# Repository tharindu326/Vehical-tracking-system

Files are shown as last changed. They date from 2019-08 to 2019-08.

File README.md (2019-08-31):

# Vehical-tracking-system

System will detect vehicle’s movements using the vibrations of vehicle and then notify the owner in any case of unidentified movements.

Here I used Peizo to identify vibrations using amplified voltage variations, GPS module (Ublox neo-6m) to identify the coordinates of the location and then GSM (SIM800) module to transmit the data to the mobile device.

And used a mobile application (Android) to request the real time location of the vehicle at any time. And initiation of the phone number and activation can be done using the app as well as it also allows the owner to turn on and off the system at any time.

Arduino UNO was used as the microcontroller and Android studio was used to program the application. Buck converter is used to power up the GPS and GSM modules since its slightly power hungry. Vehicle GPS antenna was used to achieve  more reliable signal strength.

Open Source Licence

Feel free to use this codes and let me know your comments.

[Author] Tharindu Ekanayake _ tharindu326@gmail.com

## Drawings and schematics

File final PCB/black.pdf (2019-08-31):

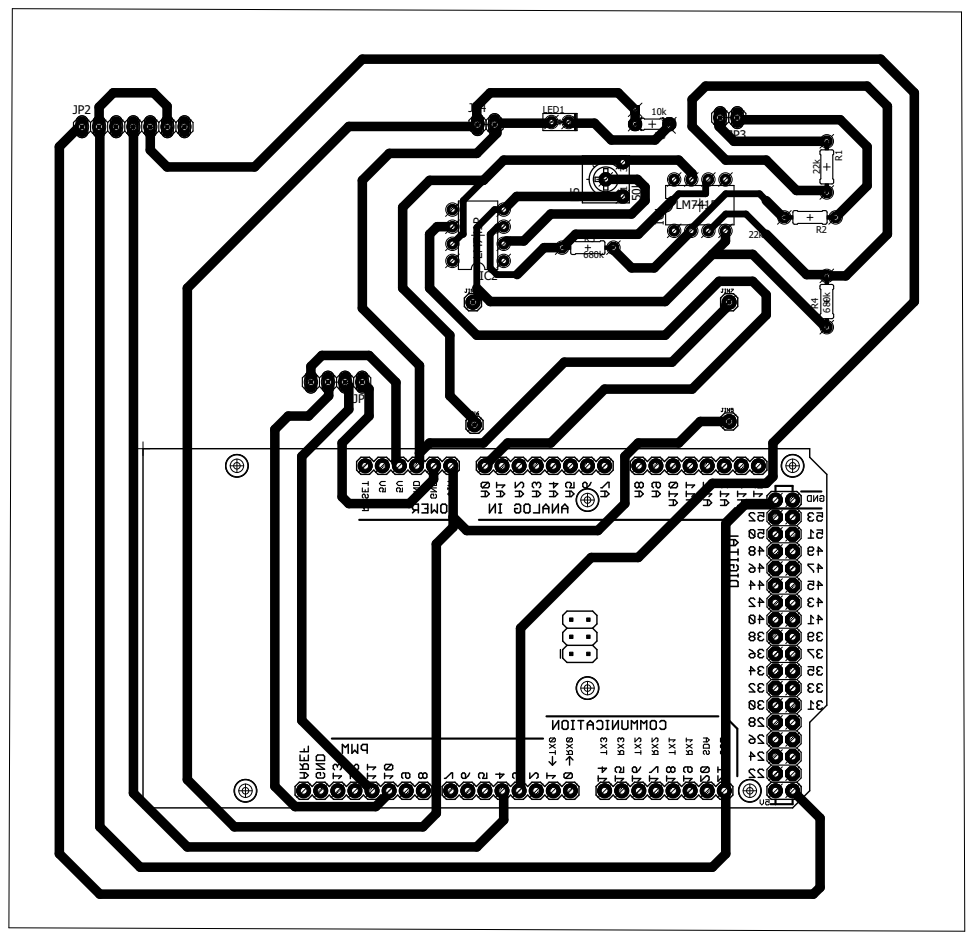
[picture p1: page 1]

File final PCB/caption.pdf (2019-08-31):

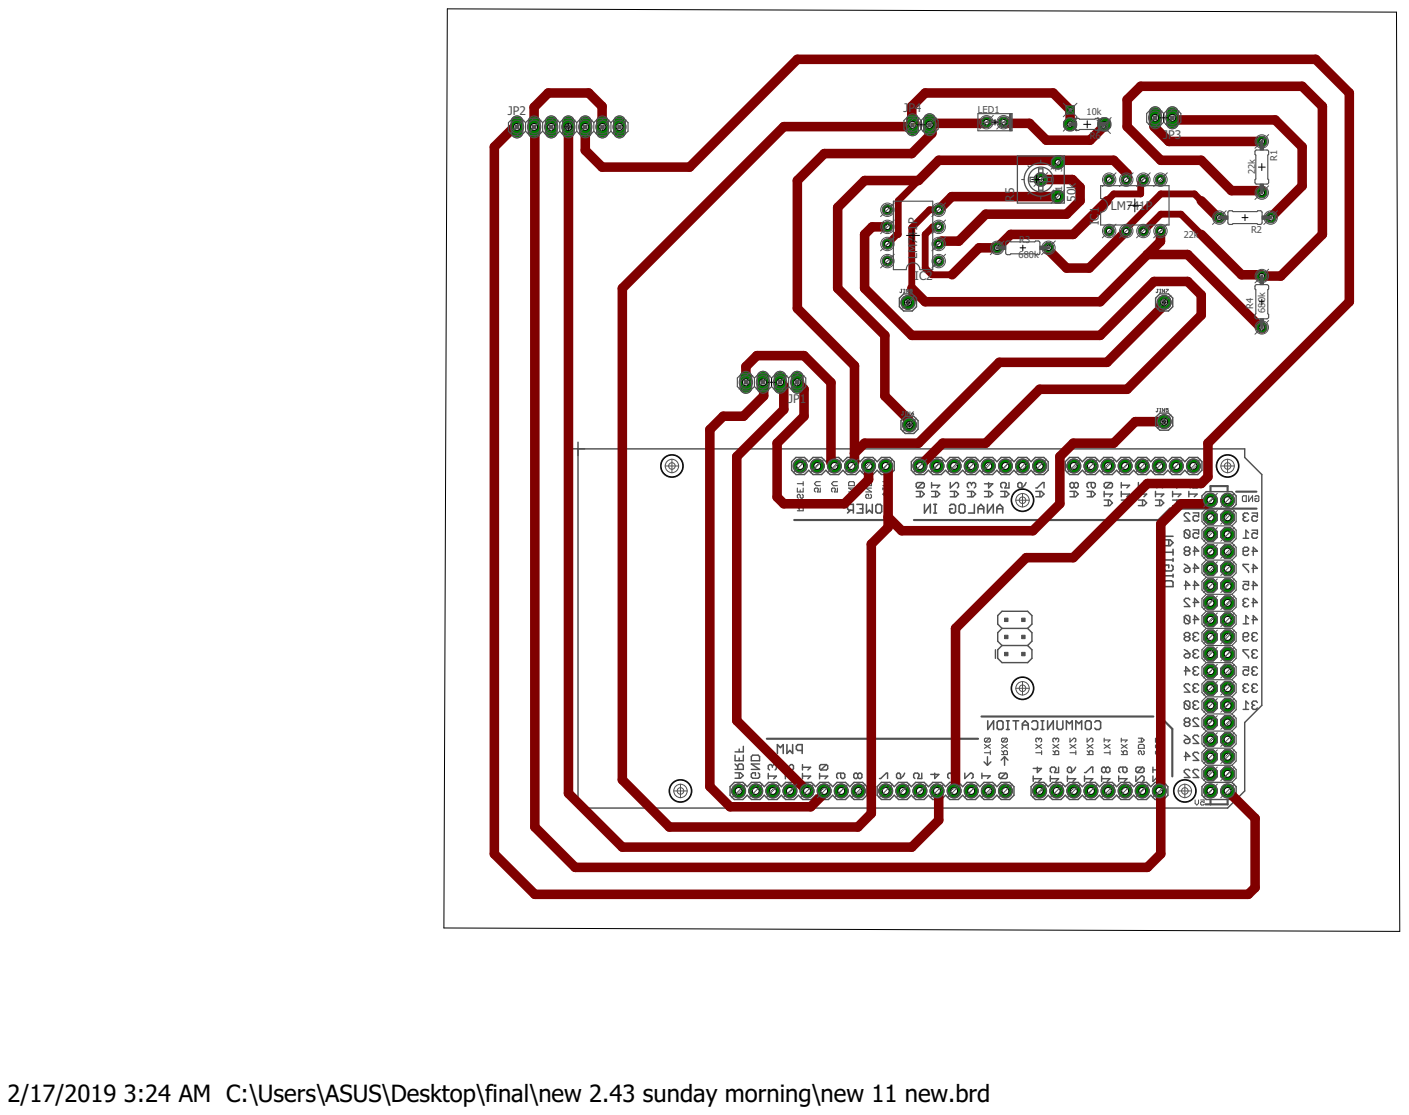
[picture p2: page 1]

2/17/2019 3:24 AM C:\Users\ASUS\Desktop\final\new 2.43 sunday morning\new 11 new.brd

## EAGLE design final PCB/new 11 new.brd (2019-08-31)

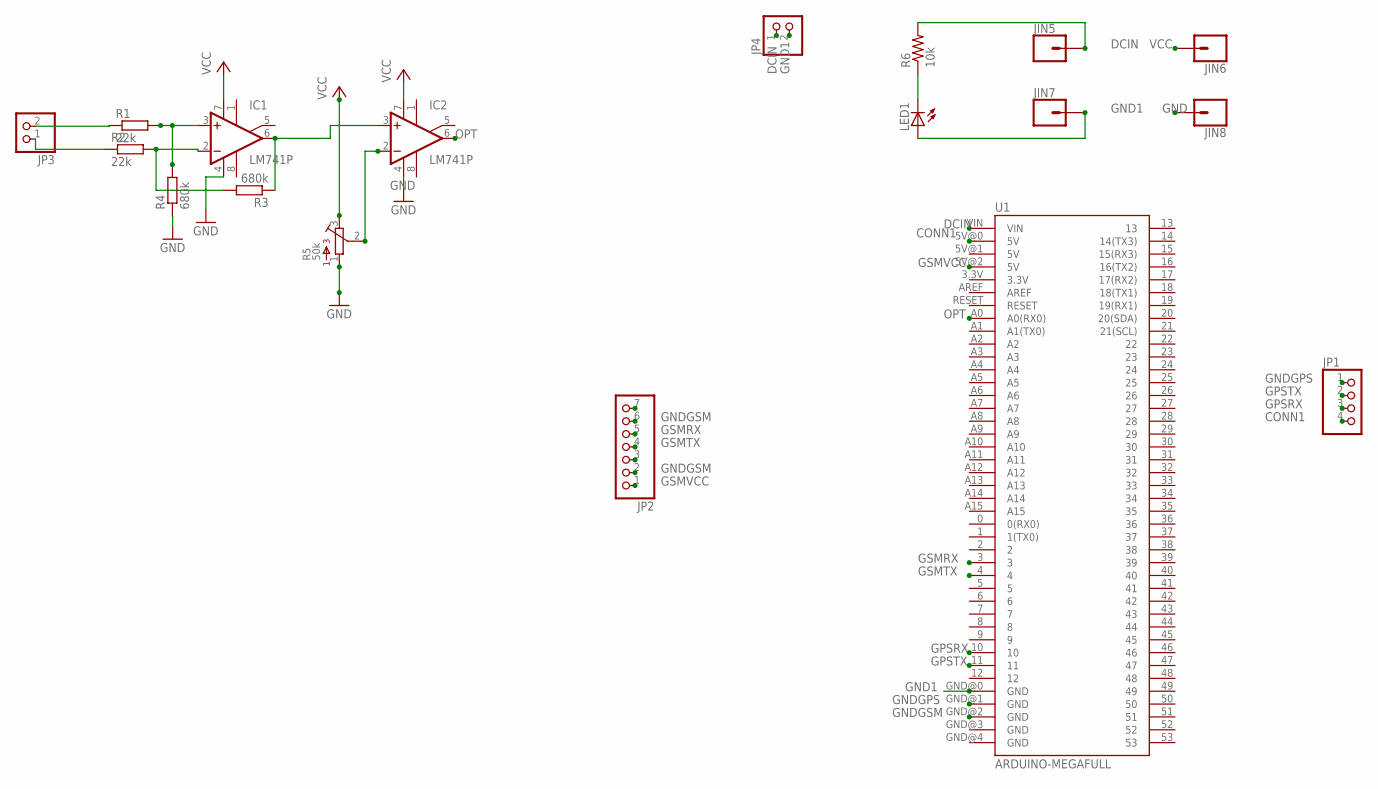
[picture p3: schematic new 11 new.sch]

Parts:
IC1, IC2: LM741P; DIL08
JIN5, JIN6, JIN7, JIN8: CONN_01; 1X01
JP1: PINHD-1X4; 1X04
JP2: PINHD-1X7; 1X07
JP3, JP4: PINHD-1X2; 1X02
LED1: LEDSQR2X5; LED2X5
R1, R2: 22k; 0204/7
R3, R4: 680k; 0204/7
R5: 50k; 3362H
R6: 10k; 0204/5
U1: ARDUINO-MEGAFULL; ARDUINO_MEGA

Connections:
CONN1: JP1.4, U1.5V@0 (5V)
DCIN: JIN5.1, JP4.1, R6.2, U1.VIN
GND: IC1.4 (V-), IC2.4 (V-), JIN8.1, R4.1, R5.1
GND1: JIN7.1, JP4.2, LED1.A, U1.GND@0 (GND)
GNDGPS: JP1.1, U1.GND@1 (GND)
GNDGSM: JP2.2, JP2.6, U1.GND@2 (GND)
GPSRX: JP1.3, U1.10
GPSTX: JP1.2, U1.11
GSMRX: JP2.5, U1.3
GSMTX: JP2.4, U1.4
GSMVCC: JP2.1, U1.5V@2 (5V)
unnamed: IC1.6 (OUT), IC2.3 (+IN), R3.1
unnamed: IC1.2 (-IN), R2.2, R3.2
unnamed: JP3.1, R2.1
unnamed: LED1.K (C), R6.1
unnamed: JP3.2, R1.1
unnamed: IC2.2 (-IN), R5.2
unnamed: IC1.3 (+IN), R1.2, R4.2
OPT: IC2.6 (OUT), U1.A0 (A0(RX0))
VCC: IC1.7 (V+), IC2.7 (V+), JIN6.1, R5.3

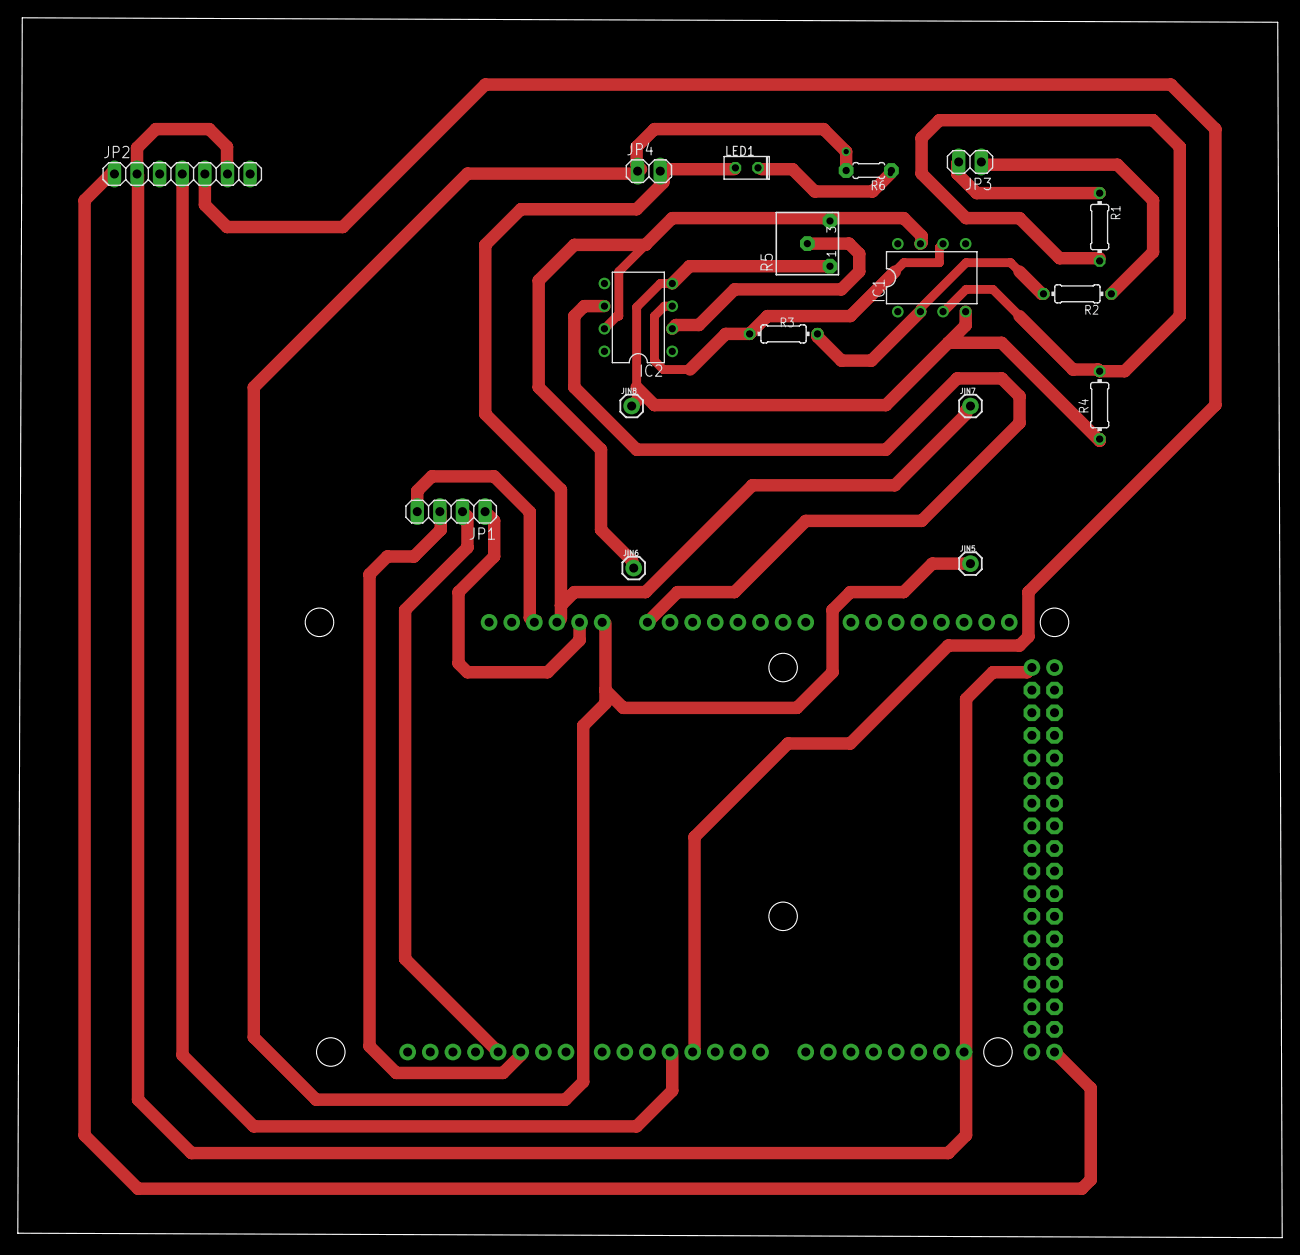
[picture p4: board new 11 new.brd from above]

Board: 2 copper layers, 142.0 x 137.0 mm, 18 parts (1 on the bottom side), 20 nets.

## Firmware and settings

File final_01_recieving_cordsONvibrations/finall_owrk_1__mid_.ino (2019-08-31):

#include <SoftwareSerial.h> 
#include <TinyGPS++.h> 

//int _timeout;

String _buffer; 
String number = "+94703647019"; //0727610798//0719552699//775458743
String latitude;
String longitude;
static const int RXPin = 10, TXPin = 11;
static const uint32_t GPSBaud = 9600;
int piezo =  A0;//analog pin

// The TinyGPS++ object
TinyGPSPlus gps;

// The serial connection to the GPS device
//SoftwareSerial ss(RXPin, TXPin);
// The serial connection to the SIM device

SoftwareSerial sim(11, 10);
void setup(){ 
   Serial.begin(9600);
   Serial1.begin(GPSBaud);
   sim.begin(9600);
   delay(1000);
   pinMode(piezo,INPUT);
   
   
   Serial.begin(9600); // connect serial 
   Serial.println("The GPS Received Signal:"); 
   //_buffer.reserve(50); //allocate a buffer in memory
   Serial.println("GSM System Started...");
   //Serial.begin(9600);
}


void loop(){
  //delay (100);
 checkPiezo();
 ReceiveGPS();
}


void ReceiveGPS()
{
 
  
  // This sketch displays information every time a new sentence is correctly encoded.
   while (Serial1.available() > 0){
    gps.encode(Serial1.read());
    if (gps.location.isUpdated()){
      latitude = String(gps.location.lat(), 6); 
      longitude = String(gps.location.lng(), 6); 
      //SendMessage();
     // delay(1000); //after each 10 sec send the GPS coords  
      //Serial.println("GSM System Started..");                                                                                                                                                                                                                                            
    //  Serial.print("Latitude= "); 
    //  Serial.print(latitude);
    // Serial.print(" Longitude= "); 
    //  Serial.println(longitude);
      
    }
}
}

void SendMessage()
{
  Serial.println ("Sending Message");
  sim.println("AT+CMGF=1");    //Sets the GSM Module in Text Mode
 // delay(100);
  //Serial.println ("Set SMS Number");
  sim.println("AT+CMGS=\"" + number + "\"\r"); //Mobile phone number to send message
 delay(100);
  //String SMS = String latitude,String longitude
  sim.println("VEHICLE IS ON MOVE...............                                    http://www.google.com/maps/place/"+latitude+","+longitude);//send the sms
 delay(100);
  sim.println((char)26);// ASCII code of CTRL+Z=substitut
  delay(100);
//  _buffer = _readSerial();//function for read SMS
}

void checkPiezo()
{
  int pzin=analogRead(A0);
  Serial.println(pzin);
   if(pzin>900) 
     tutu();
  }
void tutu()
 {Serial.print("Latitude= "); 
   Serial.print(latitude);
   Serial.print(" Longitude= "); 
   Serial.println(longitude);
   SendMessage();
   delay(20000);
   
 }

      
 
/*String _readSerial() {
  _timeout = 0;
  while  (!sim.available() && _timeout < 12000  );//Checks to see if there is a SMS messages on the SIM card to be read, and reports back the number of characters in the message.
  {
    delay(13);
    _timeout++;
  }
  if (sim.available()) {
    return sim.readString();//read th strings in available sms and equal it to _buffr
  }
}*/

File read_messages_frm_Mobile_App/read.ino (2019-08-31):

 #include <SoftwareSerial.h>
 #include <TinyGPS++.h> 
 SoftwareSerial sim(11, 10);  
 String Arsp, Grsp;
 String string1  ;
 
void setup() {
  Serial.begin(9600);
  sim.begin(9600);
  Serial.println("Testing GSM SIM800L");
  sim.begin(9600);
  sim.println("AT"); //checking
  delay(1000);
  sim.println("AT+CMGF=1");  //Set to Text mode
  delay(1000);
  sim.println("AT+CNMI=1, 2, 0, 0, 0"); //Set to notification for new message, New message indication
  digitalWrite(5,HIGH);

}

void loop() {
  if(sim.available()) {
    //Check if GSM Send any data
    Grsp = sim.readString(); //Read data received from SIM800L GSM Module
    Serial.print(Grsp); //Print string which received from GSM (sms, sender, sms index, receive time, etc)
    delay(500);
          if(Grsp.indexOf("O") > 0) {
         Serial.println("on");
          digitalWrite(5,HIGH);
       //digitalWrite(LED_PIN, HIGH); // enable it
       }else if(Grsp.indexOf("F") > 0) {
         // digitalWrite(LED_PIN, LOW);// turn off
         Serial.println("off");
          digitalWrite(5,LOW);
      }else if(Grsp.indexOf("R") > 0) {
       
  }
}

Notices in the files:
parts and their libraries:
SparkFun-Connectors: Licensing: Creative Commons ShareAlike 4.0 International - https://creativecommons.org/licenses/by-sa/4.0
